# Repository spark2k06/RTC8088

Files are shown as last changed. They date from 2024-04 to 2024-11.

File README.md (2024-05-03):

# RTC8088
Real Time Clock for your PC XT. Very low profile, simple and open hardware.

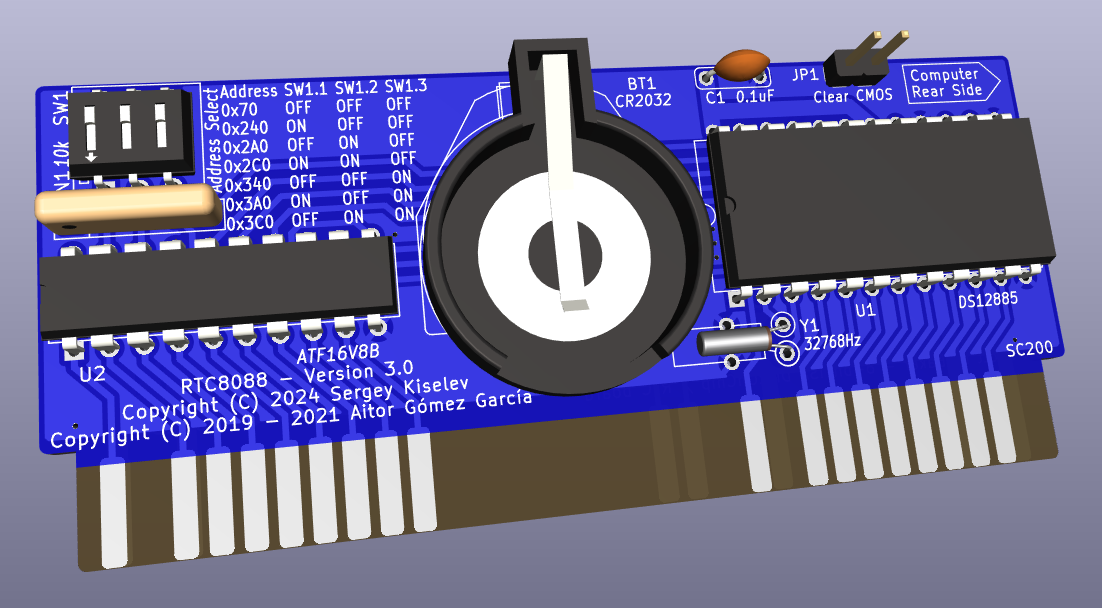
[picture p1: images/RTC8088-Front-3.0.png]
RTC8088 V3.0 3D Rendering


## Hardware Documentation

### Schematic and PCB Layout

[Schematic - Version 3.0](KiCad/RTC8088-Schematic-3.0.pdf)

[PCB Layout - Version 3.0](KiCad/RTC8088-Board-3.0.pdf)

### Swiches and Jumpers

#### SW1 - RTC I/O address select

I/O Address  | SW1.1 | SW 1.2 | SW 1.3
------------ | ----- | ------ | ------
0x70         | OFF   | OFF    | OFF
0x240        | ON    | OFF    | OFF
0x2A0        | OFF   | ON     | OFF
0x2C0        | ON    | ON     | OFF
0x340        | OFF   | OFF    | ON
0x3A0        | ON    | OFF    | ON
0x3C0        | OFF   | ON     | ON
Reserved     | ON    | ON     | ON

* Note 1: The table above gives the addresses in the supplied SPLD fuse map. The selection can be changed by reprogramming the SPLD
* Note 2: "Reserved" address is set to 0x70 in the supplied SPLD fuse map. It is recommended to use this setting when adding a custom I/O address to the SPLD

#### JP1 - Clear CMOS

Position       | Description
-------------- | -----------------
open (default) | Normal operation
closed         | Clear NVRAM memory

### Bill of Materials

#### Version 3.0

[RTC8088 project on Mouser.com](https://www.mouser.com/ProjectManager/ProjectDetail.aspx?AccessID=2877d21cfa) - View and order all components except of the FDC and the PCB.

[RTC8088 on OSH Park](https://oshpark.com/shared_projects/bAF8uwKL) - View and order the PCB.

Component type     | Reference | Description                                     | Quantity | Possible sources and notes 
------------------ | --------- | ----------------------------------------------- | -------- | --------------------------
PCB                |           | RTC8088 PCB - Version 3.0                       | 1        | Order from your favorite PCB manufacturer using provided Gerber files
Integrated Circuit | U1        | DS12885+ - RTC, 24 pin DIP                      | 1        | Mouser [700-DS12885](https://www.mouser.com/ProductDetail/700-DS12885) or [700-DS12885N](https://www.mouser.com/ProductDetail/700-DS12885N)
Integrated Circuit | U2        | ATF16V8B-15PU - Simple Programmable Logic Device, 20 pin DIP | 1 | Mouser [556-AF16V8B15PU](https://www.mouser.com/ProductDetail/556-AF16V8B15PU) or GAL16V8
Quartz Crystal     | Y1        | 32768 Hz, 6 pF                                  | 1        | Mouser [815-AB26T32768KHZ6B](https://www.mouser.com/ProductDetail/815-AB26T32768KHZ6B), [520-ECS327-6-13-X](https://www.mouser.com/ProductDetail/520-ECS327-6-13-X), or [628-VT200F-6PF20PPM](https://www.mouser.com/ProductDetail/628-VT200F-6PF20PPM)
Battery Holder     | BT1       | CR2032 battery holder                           | 1        | Mouser [122-2620-GR](https://www.mouser.com/ProductDetail/122-2620-GR) or [122-2420-GR](https://www.mouser.com/ProductDetail/122-2420-GR)
Battery            | BT1       | CR2032 battery                                  | 1        | Mouser [81-CR2032](https://www.mouser.com/ProductDetail/81-CR2032), [658-CR2032](https://www.mouser.com/ProductDetail/658-CR2032), or [614-CR2032-200](https://www.mouser.com/ProductDetail/614-CR2032-200)
Capacitor          | C1        | 0.1 uF, 50V, MLCC, 5 mm pitch                   | 1        | Mouser [594-K104K15X7RF53H5](https://www.mouser.com/ProductDetail/594-K104K15X7RF53H5) or [810-FG28X7R1H104KNT6](https://www.mouser.com/ProductDetail/810-FG28X7R1H104KNT6)
Resistor Array     | RN1       | 10 kohm, bussed, 5 pin SIP                      | 1        | Mouser [652-4605X-1LF-10K](https://www.mouser.com/ProductDetail/652-4605X-1LF-10K) or [652-4605X-AP1-103LF](https://www.mouser.com/ProductDetail/652-4605X-AP1-103LF)
DIP Switch         | SW1       | DIP switch, 3 position, SPST                    | 1        | Mouser [774-2103MS](https://www.mouser.com/ProductDetail/774-2103MS)
Pin Header         | JP1       | 2 pin header, 2.54 mm pitch                     | 1        | Mouser [649-68002-102HLF](https://www.mouser.com/ProductDetail/649-68002-102HLF)
Jumper             | JP1       | Shunt, 2 pin, 2.54 mm pitch                     | 1        | Mouser [806-SX1100-B](https://www.mouser.com/ProductDetail/806-SX1100-B)
IC Socket          | U1        | 20 pin DIP, 2.54 mm pitch, 7.62 mm row spacing  | 1        | Mouser [649-DILB20P-223TLF](https://www.mouser.com/ProductDetail/649-DILB20P-223TLF)
IC Socket          | U2        | 24 pin DIP, 2.54 mm pitch, 15.24 mm row spacing | 1        | Mouser [649-DILB24P-223TLF](https://www.mouser.com/ProductDetail/649-DILB24P-223TLF)

## Software

The board is supported by the [8088 BIOS](https://github.com/skiselev/8088_bios) and [GLaTICK BIOS Extension](https://github.com/640-KB/GLaTICK).

## Release Notes

### Changes

* Version 3.0
  * Add I/O address configuration switches
  * Remove IRQ configuration jumpers and IRQ support
* Version 2.0
  * Aitor RTC8088
* Version 1.0
  * Initial version

### Known Issues

* No known issues

### Wishlist

* None so far

## Red Tape

### Licensing

RTC8088 is an open source hardware project. The hardware design itself, including schematic and PCB layout design files are licensed under the strongly-reciprocal variant of [CERN Open Hardware Licence version 2](license-cern_ohl_s_v2.txt). The SPLD code is licensed under [GNU General Public License v3](license-gpl-3.0.txt). Documentation, including this file, is licensed under the [Creative Commons Attribution-ShareAlike 4.0 International License](license-cc-by-sa-4.0.txt).

CERN-OHL-2.0-S, GPL-3.0, CC-BY-SA-4.0

## More information

### Orignal RTC8088 Project Description
https://hackaday.io/project/168972-rtc-isa-8-bits-pcxt

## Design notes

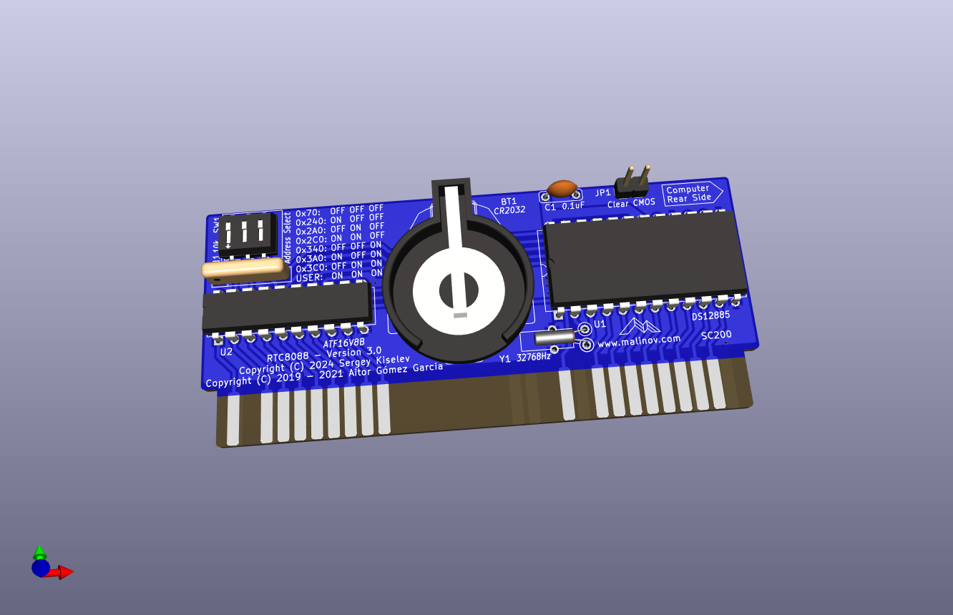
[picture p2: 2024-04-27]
KiCad/RTC8088-Front-3.0.png

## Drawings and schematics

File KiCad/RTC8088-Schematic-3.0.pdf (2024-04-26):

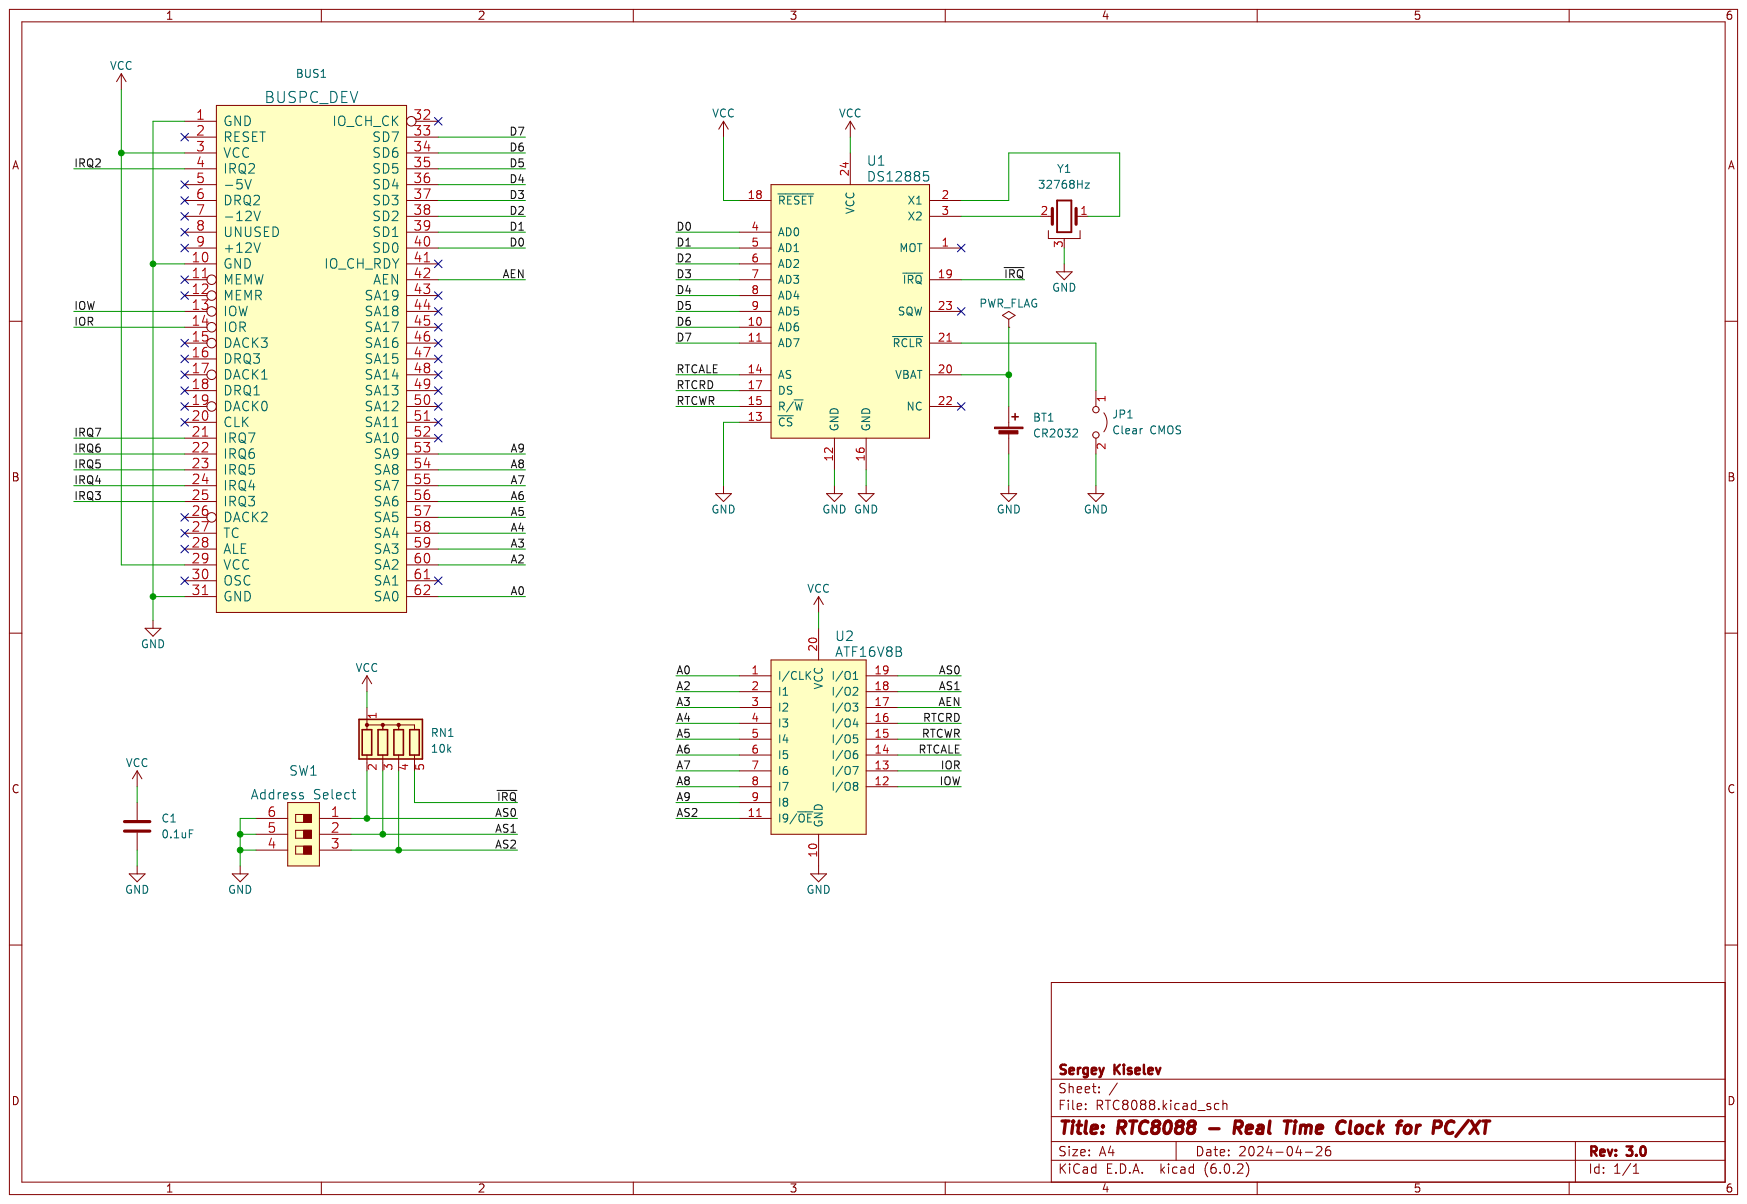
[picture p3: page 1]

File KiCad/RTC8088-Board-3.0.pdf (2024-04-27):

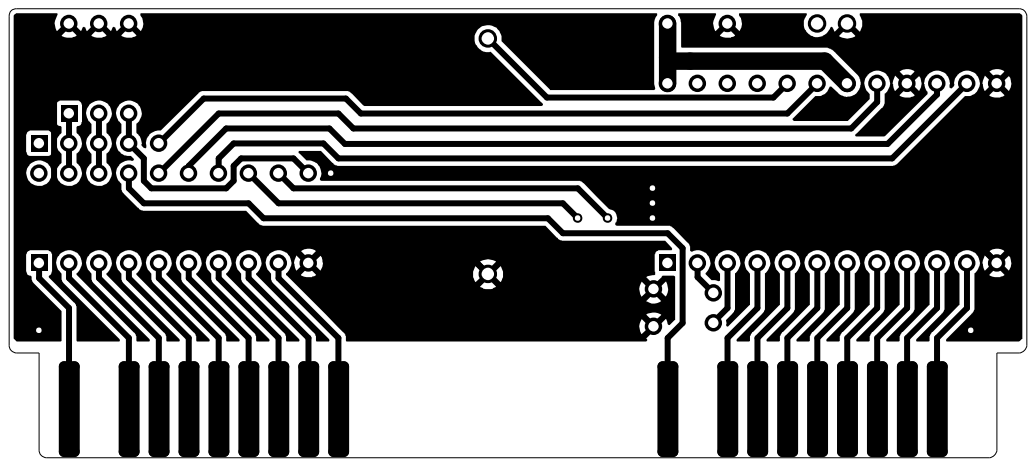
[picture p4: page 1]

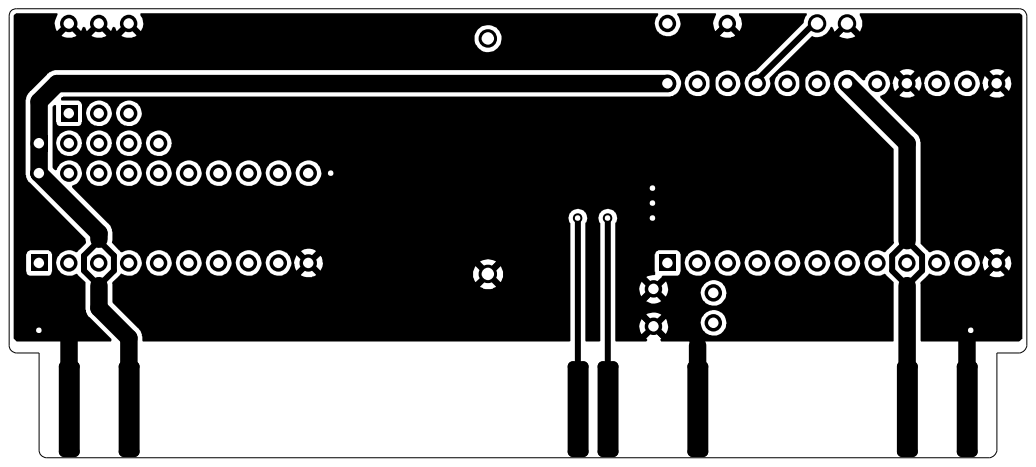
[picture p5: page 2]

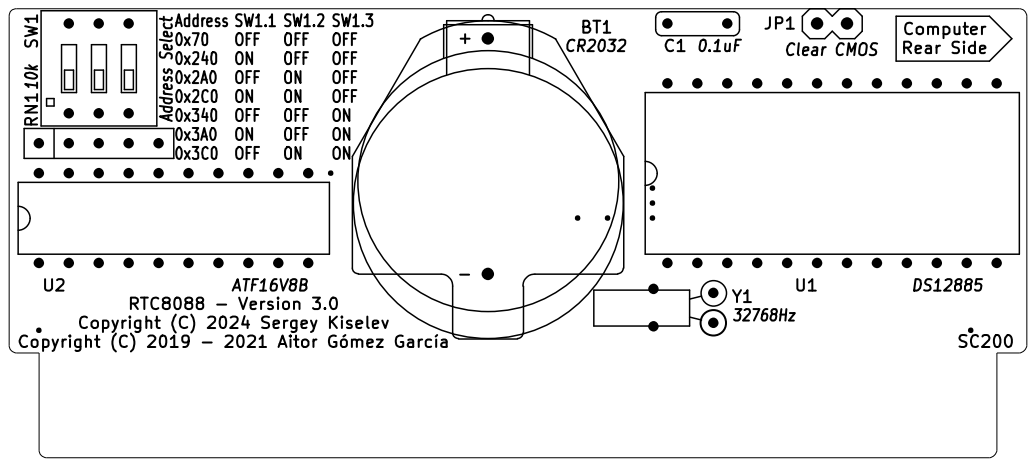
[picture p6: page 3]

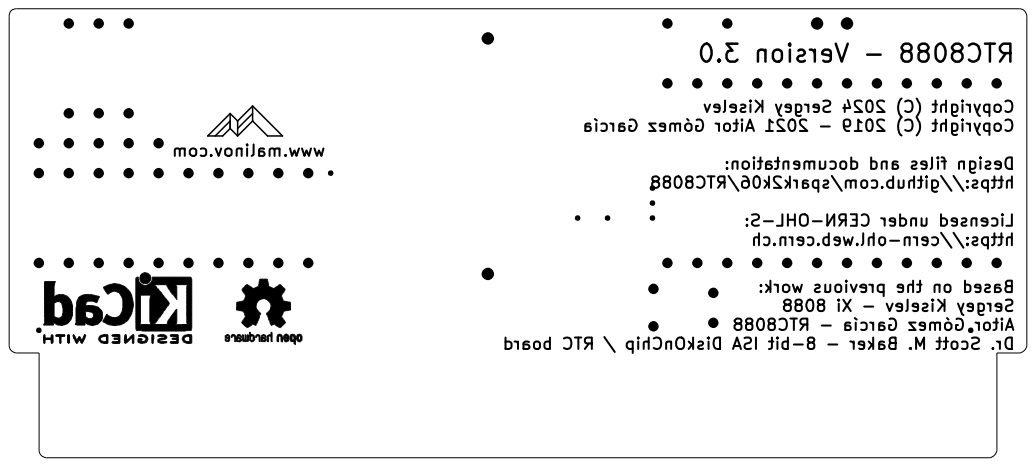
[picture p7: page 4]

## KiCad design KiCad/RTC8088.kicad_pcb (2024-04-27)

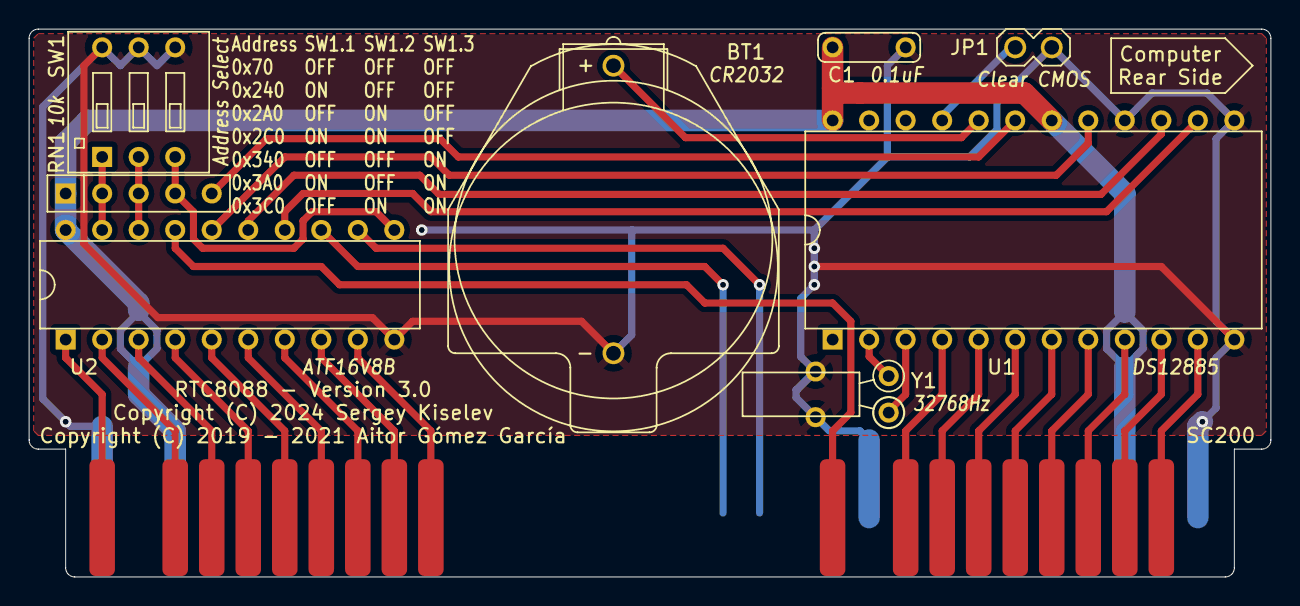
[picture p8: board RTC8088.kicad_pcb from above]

Board: 2 copper layers, 86.4 x 38.1 mm, 9 parts (0 on the bottom side), 33 nets.

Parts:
BT1: CR2032; Battery_Holder_CR2032_Universal
BUS1: BUSPC_DEV; Conn_Edge_PCB_ISA8
C1: 0.1uF; Cap_Cer_508
JP1: Clear CMOS; Conn_Pin_Header_2x1_2.54mm_NoKey
RN1: 10k; Conn_SIL5
SW1: Address Select; Switch_DIP_3_Positions
U1: DS12885; IC_DIP24_600
U2: ATF16V8B; IC_DIP20_300
Y1: 32768Hz; Crystal_32K_Horiz

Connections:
/A0: BUS1.62 (SA0), U2.1 (I/CLK)
/A2: BUS1.60 (SA2), U2.2 (I1)
/A3: BUS1.59 (SA3), U2.3 (I2)
/A4: BUS1.58 (SA4), U2.4 (I3)
/A5: BUS1.57 (SA5), U2.5 (I4)
/A6: BUS1.56 (SA6), U2.6 (I5)
/A7: BUS1.55 (SA7), U2.7 (I6)
/A8: BUS1.54 (SA8), U2.8 (I7)
/A9: BUS1.53 (SA9), U2.9 (I8)
/AEN: BUS1.42 (AEN), U2.17 (I/O3)
/AS0: RN1.2 (R1), SW1.1, U2.19 (I/O1)
/AS1: RN1.3 (R2), SW1.2, U2.18 (I/O2)
/AS2: RN1.4 (R3), SW1.3, U2.11 (I9/~OE)
/D0: BUS1.40 (SD0), U1.4 (AD0)
/D1: BUS1.39 (SD1), U1.5 (AD1)
/D2: BUS1.38 (SD2), U1.6 (AD2)
/D3: BUS1.37 (SD3), U1.7 (AD3)
/D4: BUS1.36 (SD4), U1.8 (AD4)
/D5: BUS1.35 (SD5), U1.9 (AD5)
/D6: BUS1.34 (SD6), U1.10 (AD6)
/D7: BUS1.33 (SD7), U1.11 (AD7)
/IOR: BUS1.14 (IOR), U2.13 (I/O7)
/IOW: BUS1.13 (IOW), U2.12 (I/O8)
/RTCALE: U1.14 (AS), U2.14 (I/O6)
/RTCRD: U1.17 (DS), U2.16 (I/O4)
/RTCWR: U1.15 (R/~W), U2.15 (I/O5)
/~IRQ: RN1.5 (R4), U1.19 (~IRQ)
GND: BT1.2 (-), BUS1.1 (GND), BUS1.10 (GND), BUS1.31 (GND), C1.2, JP1.2 (B), SW1.4, SW1.5, SW1.6, U1.12 (GND), U1.13 (~CS), U1.16 (GND), U2.10 (GND), Y1.3
unnamed: BT1.1 (+), U1.20 (VBAT)
unnamed: JP1.1 (A), U1.21 (~RCLR)
unnamed: U1.2 (X1), Y1.1
unnamed: U1.3 (X2), Y1.2
VCC: BUS1.3 (VCC), BUS1.29 (VCC), C1.1, RN1.1 (common), U1.18 (~RESET), U1.24 (VCC), U2.20 (VCC)

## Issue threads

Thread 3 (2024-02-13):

Add jumper to select the I/O address

skiselev, 2024-02-13:
Currently the project uses different SPLD bitstreams to select the RTC I/O address.
Therefore, to change the I/O address, it requires reprogramming the SPLD, which is not a viable option for most users.

I recommend two options for modifications to allow configuring the I/O addresses:

1. Simple: Use currently unused pin 19 to select between two addresses. This is a really simple change. It will require adding a jumper and a pull-up resistor on this pin.
2. More complicated: Free up 1-2 more pins. A few options here:
* Don't decode A2, and perhaps even don't decode A3. The I/O port allocation in IBM PC-compatibles is typically done with 0x10/16 addresses increments anyway. Use freed up signals to add switches or jumpers.
* Don't implement the IRQ. I don't think it is being used often, and perhaps not being used at all...

spark2k06, 2024-02-14:
Good proposals, I take note for a next version.

spark2k06, 2024-04-24:
With this version we will have 5 bits to play with the address mapping:

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

I will now think about their implementation in the SPLD.

spark2k06, 2024-04-26:
Thank you for your great contribution @skiselev, I merge your changes.

Closed 2024-04-26.

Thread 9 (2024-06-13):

DSCLOCK.SYS doesnt recognize the RTC8088 3.0 Card.

explit7, 2024-06-13:
Somehow it does not work for me.
I flashed the latest SPLD on a new ATF16V8B Chip.
It is recognized by the Micro8088 BIOS only when i set the DIP-Switches to On On On or Off Off Off.
Otherwise it is not recognized by the Micro8088 BIOS and its always Absent in BIOS.

DSCLOCK.SYS doesnt recognize it when i use Autodetection or when i use the Parameter 0X2C0
GET_RTC and SET_RTC recognized it on Port 02c0.
Very weird.

I have usual Micro8088 System with following Carts:
XTIDE, Adlib Card, Cycle Logic CGA-Graphic Card, 2xSerial, 1xParallel Controller 16C552, RTC8088 3.0

Any suggestions, what else i can test?

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

_Originally posted by @explit7 in https://github.com/spark2k06/RTC8088/issues/8#issuecomment-2166947224_

explit7, 2024-06-13:
OK found something weird. When i set the RTC8088 DIP-Switches to 02C0 - it is not recognized by the Micro8088 BIOS, but it recognized by the DSCLOCK.SYS.

Very weird...

skiselev, 2024-06-17:
The 8088 BIOS code and this DSCLOCK.SYS code are mutually exclusive:

- The 8088 BIOS only supports RTC on port 0x70.
- The DSCLOCK.SYS driver does not support port 0x70. RTC8088 should be configured to use other ports when using DSCLOCK.SYS driver

Basically there are two use case:
1. The 8088 BIOS on an FE2010A or a PT8010AF based system (Micro 8088, NuXT). In this case, the RTC should be configured to port 0x70, and the 8088 BIOS RTC support should be used.
2. RTC8088 used with any other systems, e.g., the original IBM PC or XT. In this case most likely the RTC will not work on port 0x70 because the ports below 0x100 are allocated for the on-board devices. When trying to read these ports, the ISA bus data transceiver on the system board will be configured in the wrong direction - from the system board to the ISA bus. This will create a bus contention and might be even dangerous, as both said transceiver and the RTC will try to drive the data bus... Therefore, for these systems, other ports - 0x240, 0x2A0, 0x2C0, 0x340, 0x3A0, or 0x3C0 should be used instead. Also, since the system BIOS on these systems wouldn't have a built-in RTC support, the DSCLOCK.SYS should be used.

There are some other [systems and motherboards based on the FE2010A or the PT8010AF chipsets](https://github.com/skiselev/Proton_Turbo_XT), where the RTC can be safely configured on port 0x70... But likely this is a minority of the motherboard, and given the risks described above, I deliberately decided not to enable port 0x70 support in DSCLOCK.SYS... It is not that difficult to enable port 0x70 support though, and I can do that if you feel that it is desired.

I'll update your https://github.com/skiselev/8088_bios/issues/71 issue separately, as it doesn't have anything to do with the DSCLOCK.SYS driver.

explit7, 2024-06-17:
OK, i understand, @skiselev  For me this was not clear, why in Micro8088 BIOS the RTC should be default on 0x70, when DSCLOCK.SYS can't detect it on 0x70.
Now i understand, that DSCLOCK.SYS is not meant for use with Micro8088 and NuXT.

My wish was ,that the RTC is detected in Micro8088 and detected by DSCLOCK.SYS.
If you can change DSCLOCK.SYS to enable detection on 0x70 Port -that would be nice.
If not - i will stay on GET_RTC.EXE and SET_RTC.EXE

The both tools detect my RTC on Port 0x2C0 (what is wrong), but they work.
Of course DSCLOCK.SYS would me more reliable.
Maybe put a small check? When FE2010A / PT8010AF is detected - look on Port 0x70 ?

Thanks

skiselev, 2024-06-17:
It's not a problem to add port 0x70 support. Detecting FE2010A / PT8010AF might not be trivial... The 8088 BIOS does that, but it already knows that it will find either one of these chipsets, and just checks for a small difference in their behavior

explit7, 2024-06-17:
Yes, maybe changinging DSCLOCK.SYS to support 0x70 Port would be the easiest solution!

skiselev, 2024-06-18:
I added I/O port 0x70 support in the latest driver. It doesn't show in the usage/help, because I think it is somewhat of an exception, and I don't want users to get bad ideas ;)

explit7, 2024-06-18:
> I added I/O port 0x70 support in the latest driver. It doesn't show in the usage/help, because I think it is somewhat of an exception, and I don't want users to get bad ideas ;)

Thanks @skiselev for your change and thanks for @spark2k06 for quick merging!
DSCLOCK.SYS now works on my Port 0x70 and seems to work more reliable then previous combo (GET_RTC / SET_RTC).
GET_RTC / SET_RTC have worked also, but detected the RTC8088 Module on Port 02C0, which was wrong...

I close the issue now.

Closed 2024-06-18.

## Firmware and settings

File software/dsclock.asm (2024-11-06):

;=========================================================================
; clock.asm - MS-DOS Clock driver 
;-------------------------------------------------------------------------
;
; Compiles with NASM 2.13.02, might work with other versions
;
; Copyright (C) 2024 - Sergey Kiselev.
; Provided for hobbyist use with the RTC8088 boards.
;
; This program is free software: you can redistribute it and/or modify
; it under the terms of the GNU General Public License as published by
; the Free Software Foundation, either version 3 of the License, or
; (at your option) any later version.
;
; This program is distributed in the hope that it will be useful,
; but WITHOUT ANY WARRANTY; without even the implied warranty of
; MERCHANTABILITY or FITNESS FOR A PARTICULAR PURPOSE.  See the
; GNU General Public License for more details.
;
; You should have received a copy of the GNU General Public License
; along with this program.  If not, see <http://www.gnu.org/licenses/>.
;
;=========================================================================

	cpu	8086

;-------------------------------------------------------------------------
; RTC default I/O port
default_io_port	equ	240h

;-------------------------------------------------------------------------
; locations in RTC and NVRAM
cmos_seconds	equ	00h	; seconds location in RTC
cmos_alarm_secs	equ	01h	; alarm seconds location in RTC
cmos_minutes	equ	02h	; minutes location in RTC
cmos_alarm_mins	equ	03h	; alarm minutes location in RTC
cmos_hours	equ	04h	; hours locaiton in RTC
cmos_alarm_hrs	equ	05h	; alarm hours location in RTC
cmos_day	equ	06h	; day location in RTC
cmos_date	equ	07h	; date location in RTC
cmos_month	equ	08h	; month location in RTC
cmos_year	equ	09h	; year location in RTC
cmos_floppy	equ	10h	; floppy type byte
cmos_equip	equ	14h	; equipment byte
cmos_config_a	equ	2Dh	; BIOS configuration byte A
cmos_sum_hi	equ	2Eh	; checksum of bytes 10h - 20h - high byte
cmos_sum_lo	equ	2Fh	; checksum of bytes 10h - 20h - low byte 
cmos_century	equ	32h	; centry location in RTC (DS12C887 only)

;-------------------------------------------------------------------------
; RTC control register and their bits
cmos_control_a	equ	0Ah	; RTC control A register
cmos_uip	equ	80h	; RTC update in progress bit
cmos_control_b	equ	0Bh	; RTC control B register
cmos_dse	equ	01h	; RTC daylight savings enable bit
cmos_24hours	equ	02h	; RTC 24 hours format (1 = 24 hours, 0 = 12)
cmos_uie	equ	10h	; RTC update ended interrupt enable bit
cmos_aie	equ	20h	; RTC alarm interrupt enable bit
cmos_pie	equ	40h	; RTC periodic interrupt enable bit
cmos_set	equ	80h	; RTC set bit (0 = normal operation, 1 = set)
cmos_control_c	equ	0Ch	; RTC control C register
cmos_uf		equ	20h	; RTC update ended interrupt flag
cmos_af		equ	40h	; RTC alarm interrupt flag
cmos_pf		equ	80h	; RTC periodic interrupt flag
cmos_control_d	equ	0Dh	; RTC control D register
cmos_vrt	equ	80h	; RTC vrt bit (1 = battery is OK)

;-------------------------------------------------------------------------
; Device driver - Request header - common fields (13 bytes)
cmdlen		equ	0	; Length of this command (1 byte)
unit		equ	1	; Subunit Specified (1 byte)
cmd		equ	2	; Command Code (1 byte)
status		equ	3	; Status (2 bytes / 1 word)
reserved	equ 	5	; Reserved (8 bytes)
; Device driver - Request header - Init function
num_units	equ	13	; Number of units (1 byte)
end_addr	equ	14	; End address of the driver (dword/4 bytes)
cmd_addr	equ	18	; Pointer to command line arguments + CR/LF
; Device driver - Request header - Read/Write functions
transfer_addr	equ	14	; Transfer address (dword/4 bytes)

;-------------------------------------------------------------------------
; Device driver - Commands and status
cmd_init	equ	0h	; "Init" command
cmd_read	equ	4h	; "Read" command
cmd_write	equ	8h	; "Write" command
status_done	equ	0100h	; "Done" status, bit 8 set
status_fail	equ	800Ch	; "Error" - bit 15 set + "General Failure" - 0Ch

;-------------------------------------------------------------------------
; MS-DOS reads or writes the following 6-byte sequence to clock device:
clk_days	equ	0h	; days since 01/01/1980 - word
clk_minutes	equ	2h	; minutes - byte
clk_hours	equ	3h	; hours - byte
clk_cseconds	equ	4h	; centiseconds - byte
clk_seconds	equ	5h	; seconds - byte 

	org	0h		; device drivers start at the offset 0h

;=========================================================================
; Device driver header
;-------------------------------------------------------------------------
device_header	dw	0FFFFh, 0FFFFh	; next device pointer - last device
		dw	1000000000001000b ; driver attributes
;			|           `--- clock device
;			`--------------- character device
		dw	strategy	; strategy entry point
		dw	entry		; device driver entry point
		db	'CLOCK$  '	; device name

;=========================================================================
; Clock driver data
;-------------------------------------------------------------------------
request_ptr	dd	0		; pointer to the request header
rtc_io_port	dw	0240h		; use I/O port 240h by default
seconds		db	cmos_seconds,0	; last seconds value read or written
minutes		db	cmos_minutes,0	; last minutes value read or written
hours		db	cmos_hours,0	; last hours value read or written
day		db	cmos_day,0	; last day value read or written
date		db	cmos_date,0	; last date value read or written
month		db	cmos_month,0	; last month value read or written
year		db	cmos_year,0	; last year value read or written
century		db	cmos_century,0	; last century value read or written
num_rtc_regs	equ	($-seconds)/2	; number of RTC registers
ticks		dw	0		; initial ticks value for read time
days_in_month	db	31, 28, 31, 30, 31, 30, 31, 31, 30, 31, 30, 31

;=========================================================================
; strategy - MS-DOS calls this function first, passing the request header
;            address. This function stores that address in request_ptr
; Input:
;	ES:BX = request header address
; Output:
;	none
;-------------------------------------------------------------------------
strategy:
	mov	cs:[request_ptr],bx	; save request header address
	mov	cs:[request_ptr+2],es
	retf
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

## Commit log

2024-04-26 Version 3.0: Implement switches for configuring I/O address
    [RTC8088-B_Cu.gbl, RTC8088-B_Cu.gbr, RTC8088-B_Mask.gbr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]
2024-04-26 Add PDF printouts. Add preview of the board
2024-04-26 Fix an error in the layout. Update GitHub repo. Remove unised pads on card edge connector
    [RTC8088-B_Cu.gbr, RTC8088-B_Mask.gbr, RTC8088-B_Silkscreen.gbr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]
2024-04-26 Add Bill of Materials
2024-04-26 README: Add Mouser BoM and OshPark PCB links
2024-04-27 Update silkscreen
    [RTC8088-B_Cu.gbr, RTC8088-B_Mask.gbr, RTC8088-B_Silkscreen.gbr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]
2024-04-27 Set OSHW logo attribute to Board Only
    [RTC8088.kicad_pcb]
2024-04-27 Update silkscreen
    Added logo aitorgomez.net
    [RTC8088-B_Cu.gbr, RTC8088-B_Mask.gbr, RTC8088-B_Silkscreen.gbr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]
2024-05-02 README: Fix errors in the BoM
2024-06-09 Initial implementation of DOS clock driver
2024-11-06 Fix validation problem for 2 digit months
    Credit for this fix goes to @grimjacksl. Fixes issue #11. https://github.com/spark2k06/RTC8088/issues/11
    [dsclock.asm]

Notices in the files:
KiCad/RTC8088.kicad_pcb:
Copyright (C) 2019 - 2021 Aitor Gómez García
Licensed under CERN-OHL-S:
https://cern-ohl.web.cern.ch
